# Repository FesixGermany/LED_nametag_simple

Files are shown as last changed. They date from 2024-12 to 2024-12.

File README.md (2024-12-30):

# LED nametag  

 Since many attendees are wearing some blinky LED stuff at the Chaos Communication Congress I wanted to also make myself an eye catcher  and present a little project. It was also a good opportunity to make a proper two layer PCB again to get more practice. The goal was to have the project finished or at least functional for 38C3. Since I got asked by attendees about the tag I decided to make this documentation.
 
The result is a little PCB to be worn e.g. on a collar with the outline shaped like a bone with LEDs arranged so it spells my name.
The electronics basically consists of the following:
- TP4056 lithium charger IC for a 100mAh LiPo battery
- MPM3810 DCDC converter to lower the voltage so all LEDs can be operated in parallel without a resistor
- ATtiny24 microcontroller giving PWM to the MOSFETs that switch the individual letters and the LEDs on the back
- [Paw-connect by LeoDJ](https://github.com/LeoDJ/Paw-Connect) as the ISP interface and as another eye catching feature
- Place for a photodiode to be able to adjust the brightness of the LEDs automatically depending on the surrounding

One tricky thing was to find the right voltage for the DCDC converter output so the LEDs are not too dimm at maximum brightness and not too bright as the duty cycle of the PWM would have to be extremely small on lower brightness settings and therefore one would loose the resolution for the animations.

The firmware only got to a point where I had a single simple animation running without the integration of the mentioned photodiode. That would probably require the code to be made more efficient as the memory of the controller already is quite full.
     
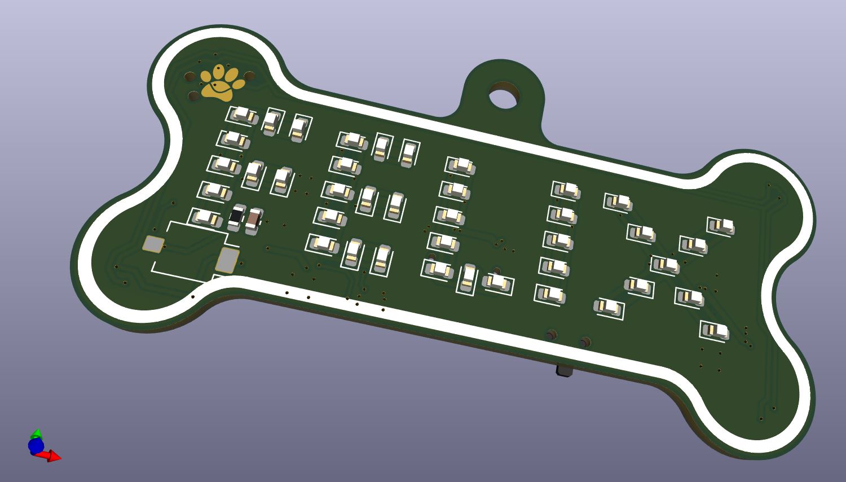
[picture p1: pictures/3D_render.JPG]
3D rendering of the PCB
   
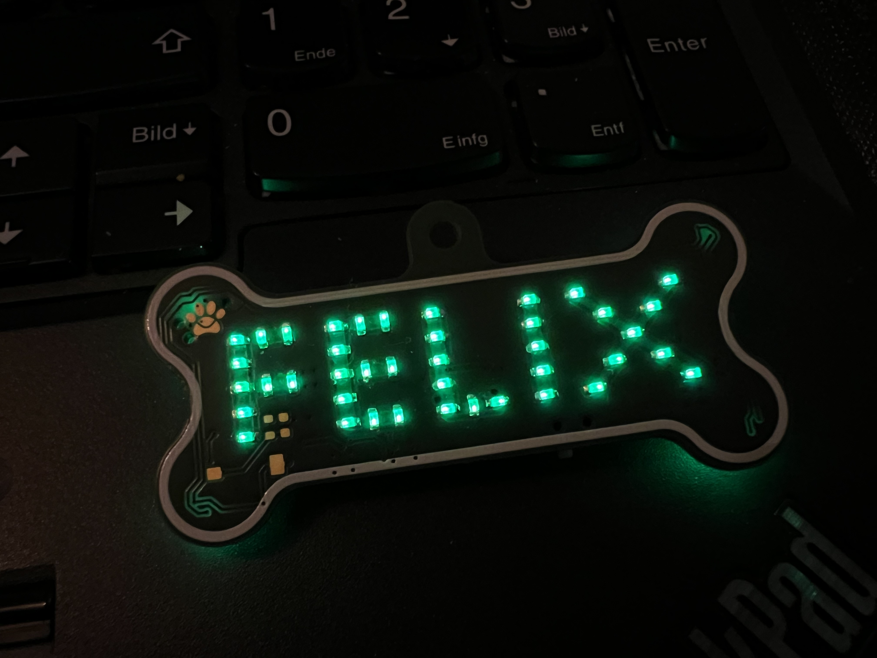
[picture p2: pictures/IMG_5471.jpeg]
Front of the PCB with lit LEDs
 
Back of the PCB with installed battery

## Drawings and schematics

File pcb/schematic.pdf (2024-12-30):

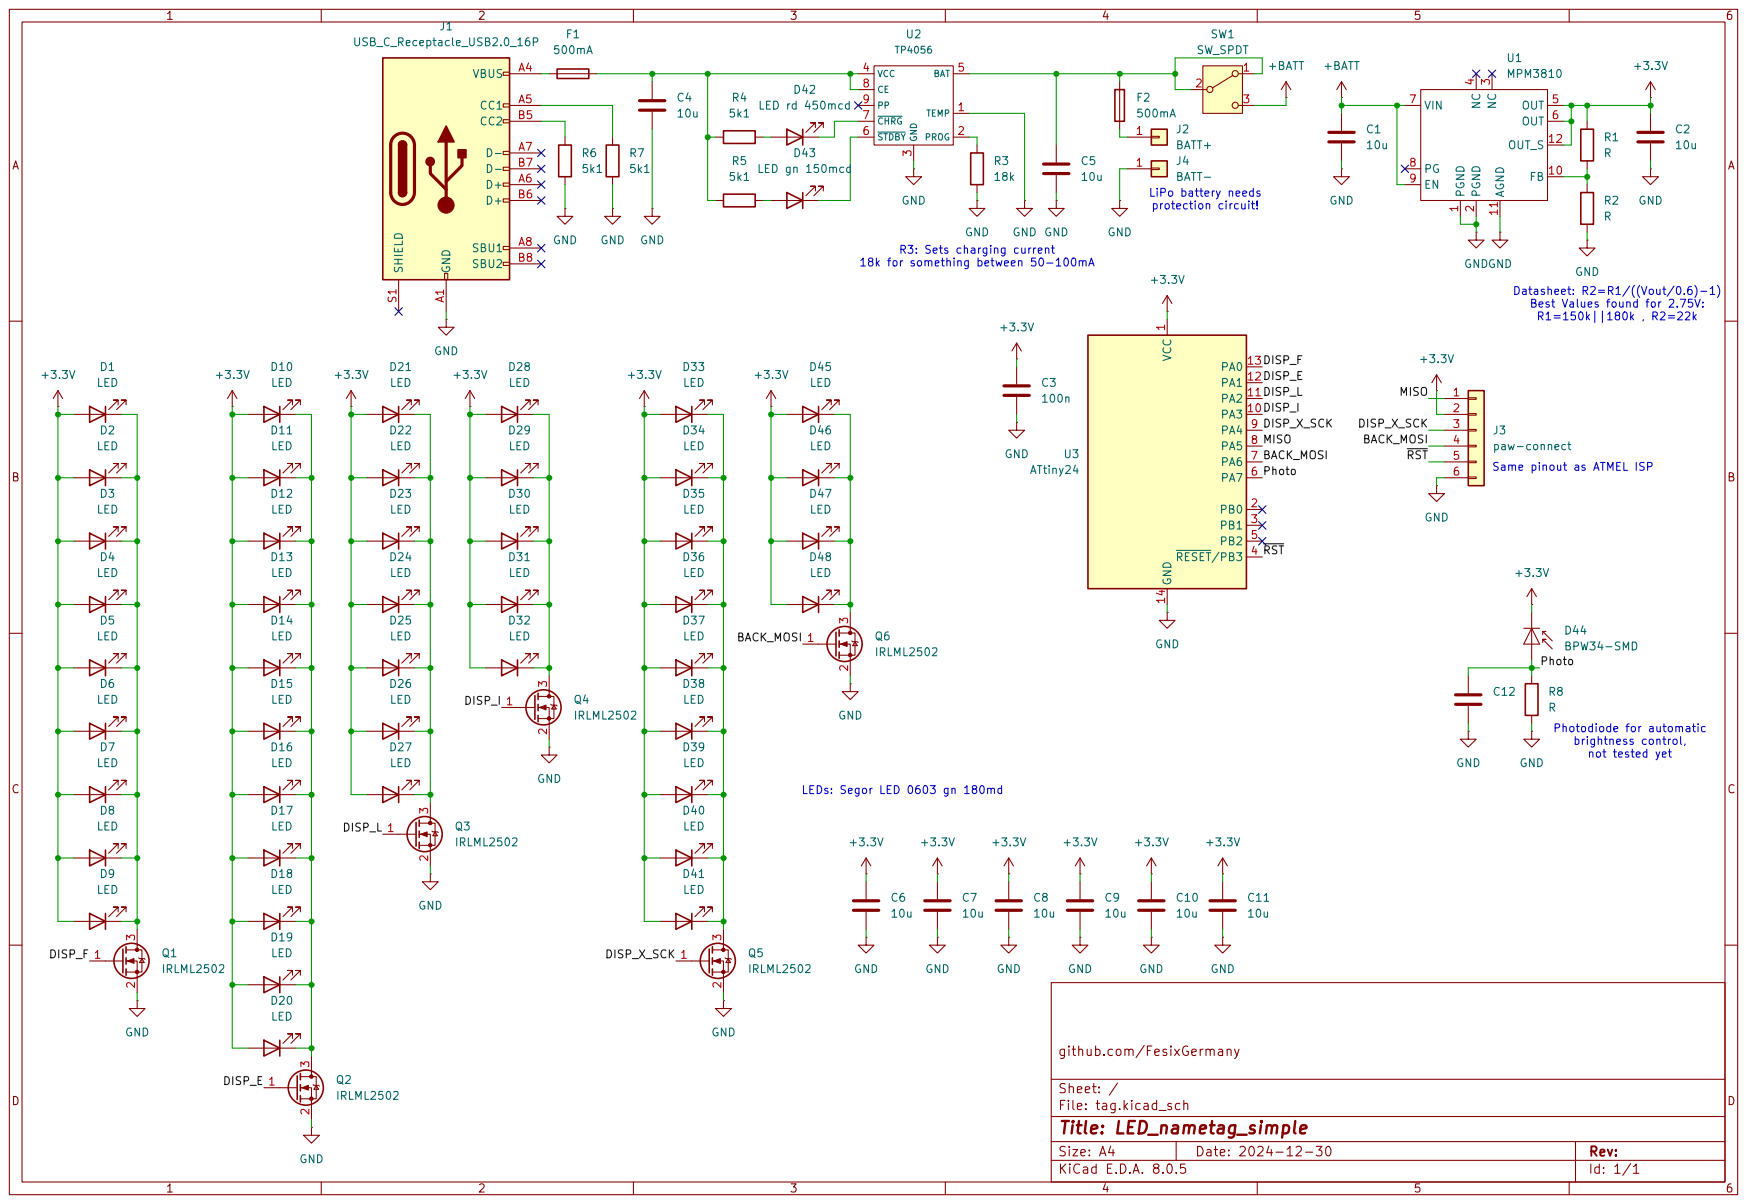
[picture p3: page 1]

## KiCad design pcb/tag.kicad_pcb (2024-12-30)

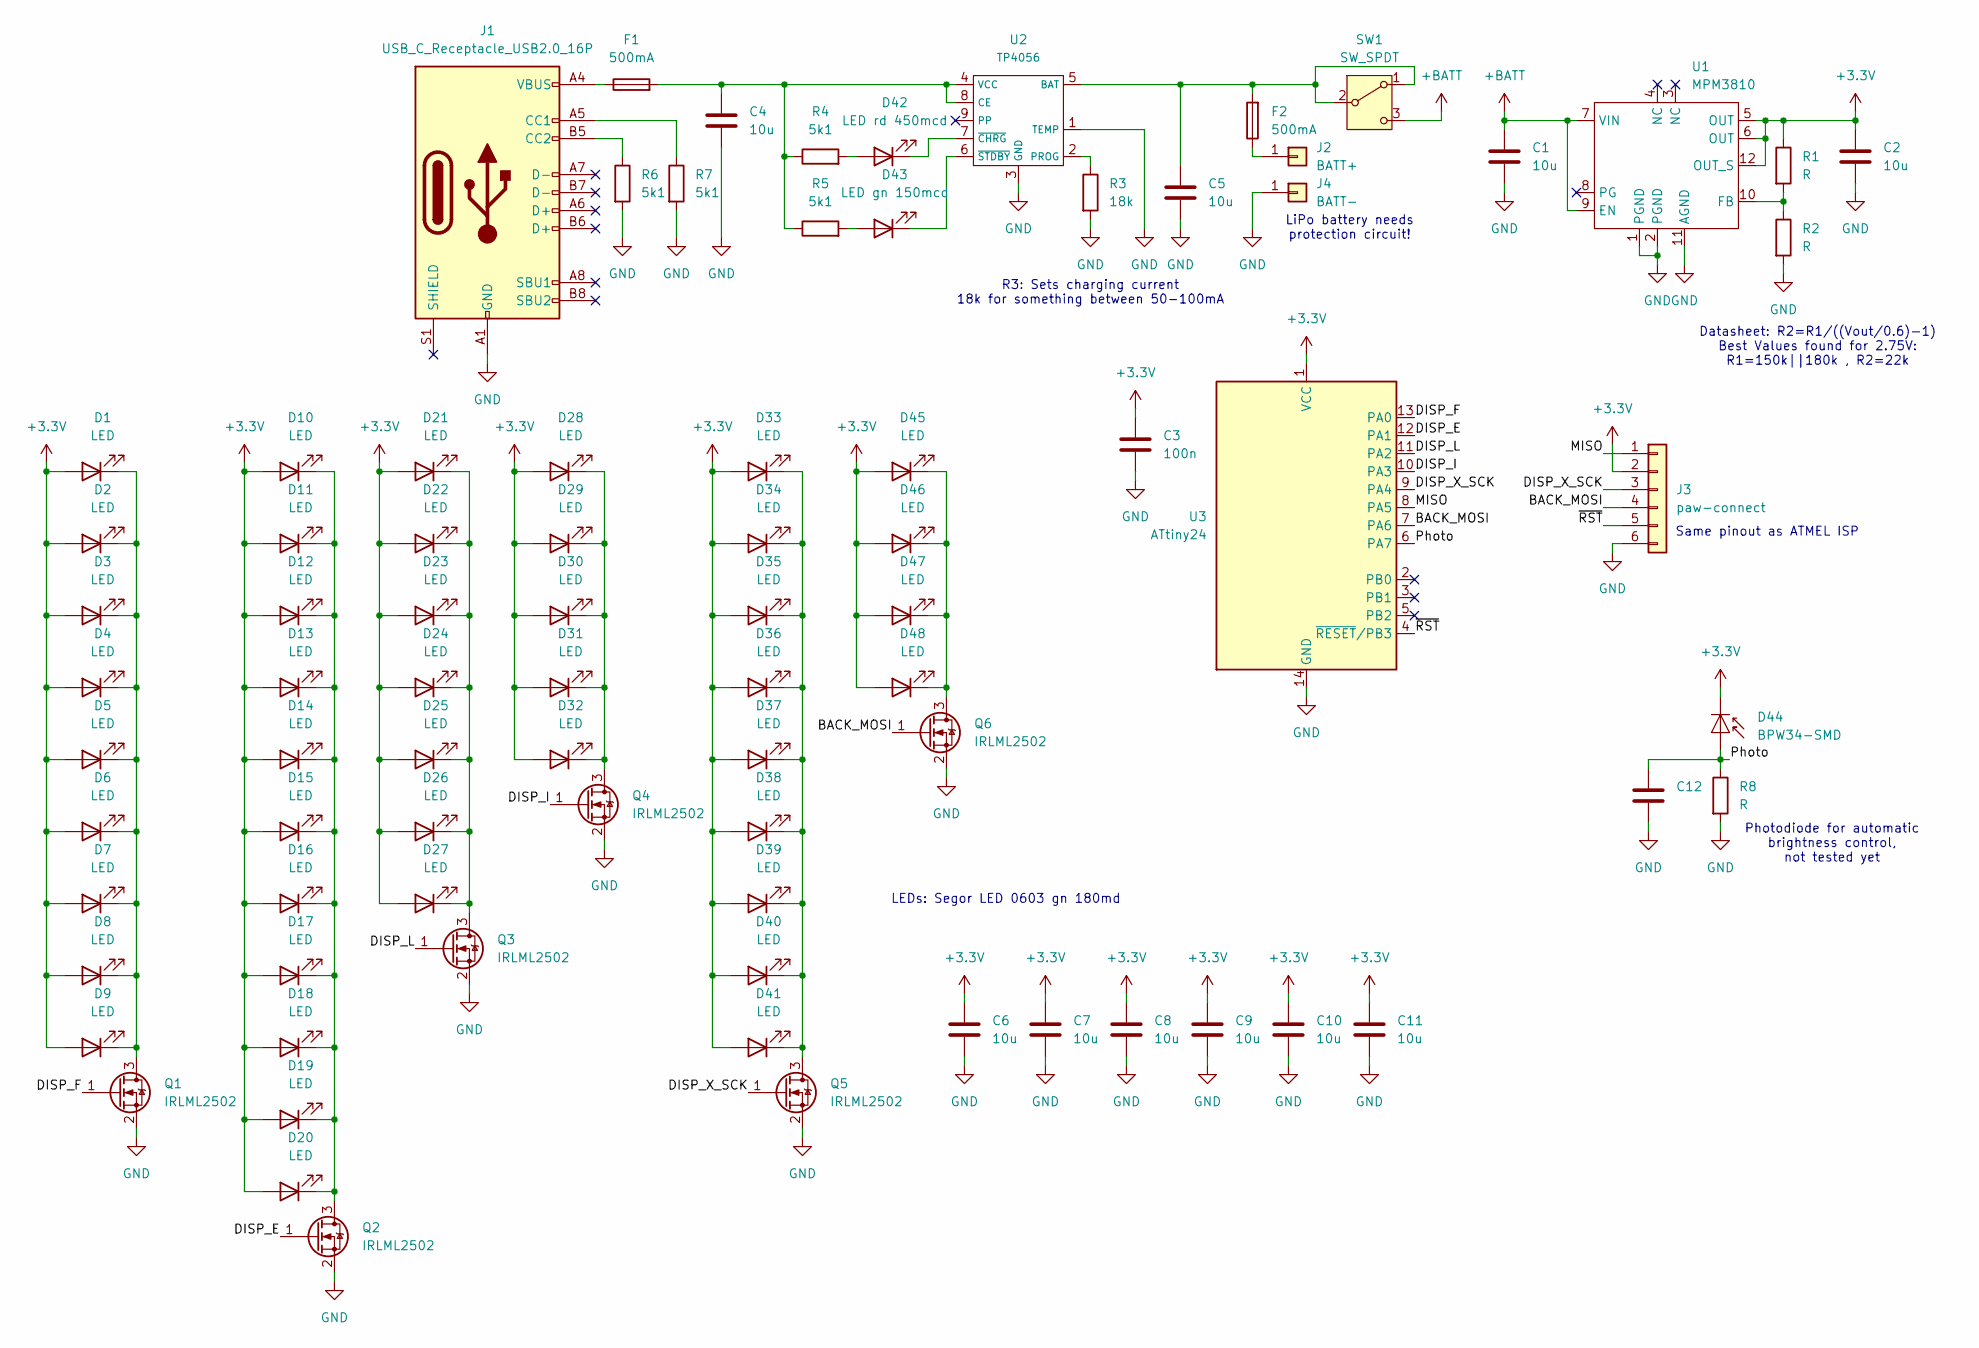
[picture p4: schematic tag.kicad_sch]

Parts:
C1, C2, C4, C5, C6, C7, C8, C9, C10, C11: 10u; C_0603_1608Metric
C3: 100n; C_0603_1608Metric
C12: C_0603_1608Metric
D1, D2, D3, D4, D5, D6, D7, D8, D9, D10, D11, D12, D13, D14, D15, D16, D17, D18, D19, D20, D21, D22, D23, D24, D25, D26, D27, D28, D29, D30, D31, D32, D33, D34, D35, D36, D37, D38, D39, D40, D41, D45, D46, D47, D48: LED; LED_0603_1608Metric
D42: LED rd 450mcd; LED_0603_1608Metric
D43: LED gn 150mcd; LED_0603_1608Metric
D44: BPW34-SMD; Osram_BPW34S-SMD
F1, F2: 500mA; Fuse_0603_1608Metric_Pad1.05x0.95mm_HandSolder
J1: USB_C_Receptacle_USB2.0_16P; USB_C_Receptacle_G-Switch_GT-USB-7010ASV
J2: BATT+; SolderWirePad_1x01_SMD_1x2mm
J3: paw-connect; Paw-Connect_RevA_TC2030-IDC-NL_2x03_P1.27mm_Vertical
J4: BATT-; SolderWirePad_1x01_SMD_1x2mm
Q1, Q2, Q3, Q4, Q5, Q6: IRLML2502; SOT-23
R1, R2, R8: R; R_0603_1608Metric
R3: 18k; R_0603_1608Metric
R4, R5, R6, R7: 5k1; R_0603_1608Metric
SW1: SW_SPDT; SW_SPDT_PCM12
U1: MPM3810
U2: TP4056; SOIC-8-1EP_3.9x4.9mm_P1.27mm_EP2.29x3mm
U3: ATtiny24; SOIC-14_3.9x8.7mm_P1.27mm

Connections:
+3.3V: C2.1, C3.1, C6.1, C7.1, C8.1, C9.1, C10.1, C11.1, D1.2 (A), D2.2 (A), D3.2 (A), D4.2 (A), D5.2 (A), D6.2 (A), D7.2 (A), D8.2 (A), D9.2 (A), D10.2 (A), D11.2 (A), D12.2 (A), D13.2 (A), D14.2 (A), D15.2 (A), D16.2 (A), D17.2 (A), D18.2 (A), D19.2 (A), D20.2 (A), D21.2 (A), D22.2 (A), D23.2 (A), D24.2 (A), D25.2 (A), D26.2 (A), D27.2 (A), D28.2 (A), D29.2 (A), D30.2 (A), D31.2 (A), D32.2 (A), D33.2 (A), D34.2 (A), D35.2 (A), D36.2 (A), D37.2 (A), D38.2 (A), D39.2 (A), D40.2 (A), D41.2 (A), D44.1 (K), D45.2 (A), D46.2 (A), D47.2 (A), D48.2 (A), J3.2, R1.1, U1.5 (OUT), U1.6 (OUT), U1.12 (OUT_S), U3.1 (VCC)
+BATT: C1.1, SW1.3 (C), U1.7 (VIN), U1.9 (EN)
/BACK_MOSI: J3.4, Q6.1 (G), U3.7 (PA6)
/DISP_E: Q2.1 (G), U3.12 (PA1)
/DISP_F: Q1.1 (G), U3.13 (PA0)
/DISP_I: Q4.1 (G), U3.10 (PA3)
/DISP_L: Q3.1 (G), U3.11 (PA2)
/DISP_X_SCK: J3.3, Q5.1 (G), U3.9 (PA4)
/MISO: J3.1, U3.8 (PA5)
/Photo: C12.1, D44.2 (A), R8.1, U3.6 (PA7)
/~RST: J3.5, U3.4 (~RESET/PB3)
GND: C1.2, C2.2, C3.2, C4.2, C5.2, C6.2, C7.2, C8.2, C9.2, C10.2, C11.2, C12.2, J1.A1 (GND), J1.A12 (GND), J1.B1 (GND), J1.B12 (GND), J3.6, J4.1, Q1.2 (S), Q2.2 (S), Q3.2 (S), Q4.2 (S), Q5.2 (S), Q6.2 (S), R2.2, R3.2, R6.2, R7.2, R8.2, U1.1 (PGND), U1.2 (PGND), U1.11 (AGND), U2.1 (TEMP), U2.3 (GND), U3.14 (GND)
unnamed: D1.1 (K), D2.1 (K), D3.1 (K), D4.1 (K), D5.1 (K), D6.1 (K), D7.1 (K), D8.1 (K), D9.1 (K), Q1.3 (D)
unnamed: D10.1 (K), D11.1 (K), D12.1 (K), D13.1 (K), D14.1 (K), D15.1 (K), D16.1 (K), D17.1 (K), D18.1 (K), D19.1 (K), D20.1 (K), Q2.3 (D)
unnamed: D21.1 (K), D22.1 (K), D23.1 (K), D24.1 (K), D25.1 (K), D26.1 (K), D27.1 (K), Q3.3 (D)
unnamed: D28.1 (K), D29.1 (K), D30.1 (K), D31.1 (K), D32.1 (K), Q4.3 (D)
unnamed: D33.1 (K), D34.1 (K), D35.1 (K), D36.1 (K), D37.1 (K), D38.1 (K), D39.1 (K), D40.1 (K), D41.1 (K), Q5.3 (D)
unnamed: D42.2 (A), R4.2
unnamed: D42.1 (K), U2.7 (~CHRG)
unnamed: D43.2 (A), R5.2
unnamed: D43.1 (K), U2.6 (~STDBY)
unnamed: D45.1 (K), D46.1 (K), D47.1 (K), D48.1 (K), Q6.3 (D)
unnamed: F1.1, J1.A4 (VBUS), J1.A9 (VBUS), J1.B4 (VBUS), J1.B9 (VBUS)
unnamed: J1.A5 (CC1), R7.1
unnamed: J1.B5 (CC2), R6.1
unnamed: F2.1, J2.1
unnamed: C5.1, F2.2, SW1.1 (A), SW1.2 (B), U2.5 (BAT)
unnamed: R1.2, R2.1, U1.10 (FB)
unnamed: C4.1, F1.2, R4.1, R5.1, U2.4 (VCC), U2.8 (CE)
unnamed: R3.1, U2.2 (PROG)

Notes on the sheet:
LiPo battery needs protection circuit!
Same pinout as ATMEL ISP
R3: Sets charging current 18k for something between 50-100mA
Datasheet: R2=R1/((Vout/0.6)-1) Best Values found for 2.75V: R1=150k||180k , R2=22k
LEDs: Segor LED 0603 gn 180md
Photodiode for automatic brightness control, not tested yet

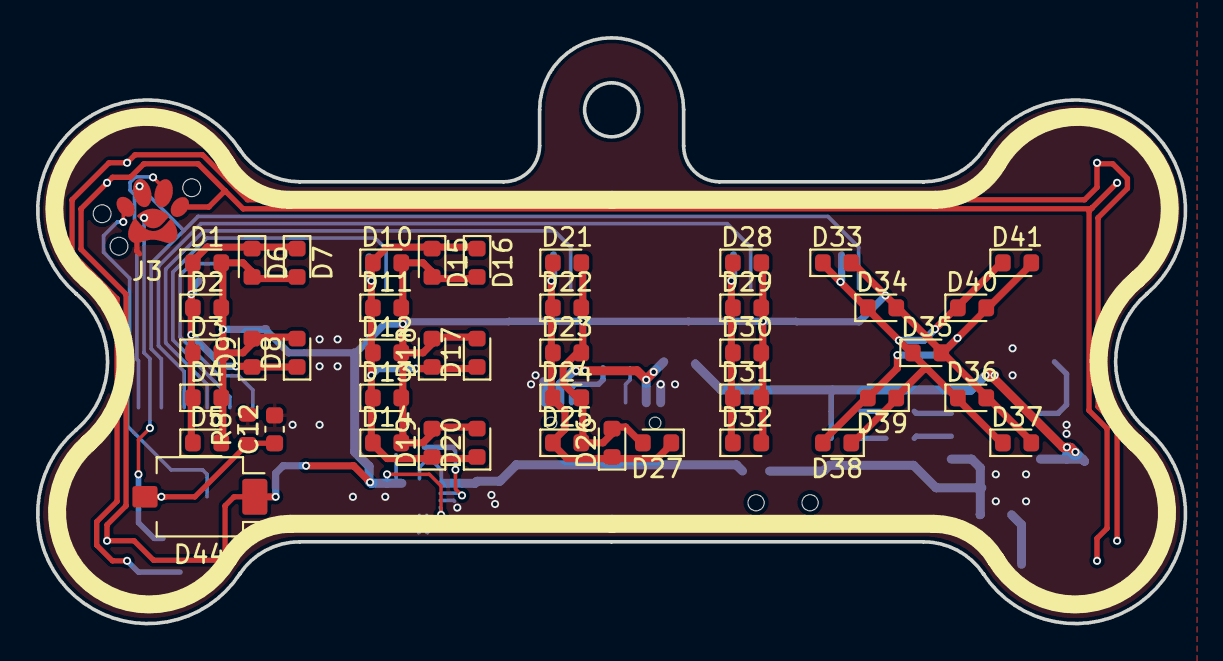
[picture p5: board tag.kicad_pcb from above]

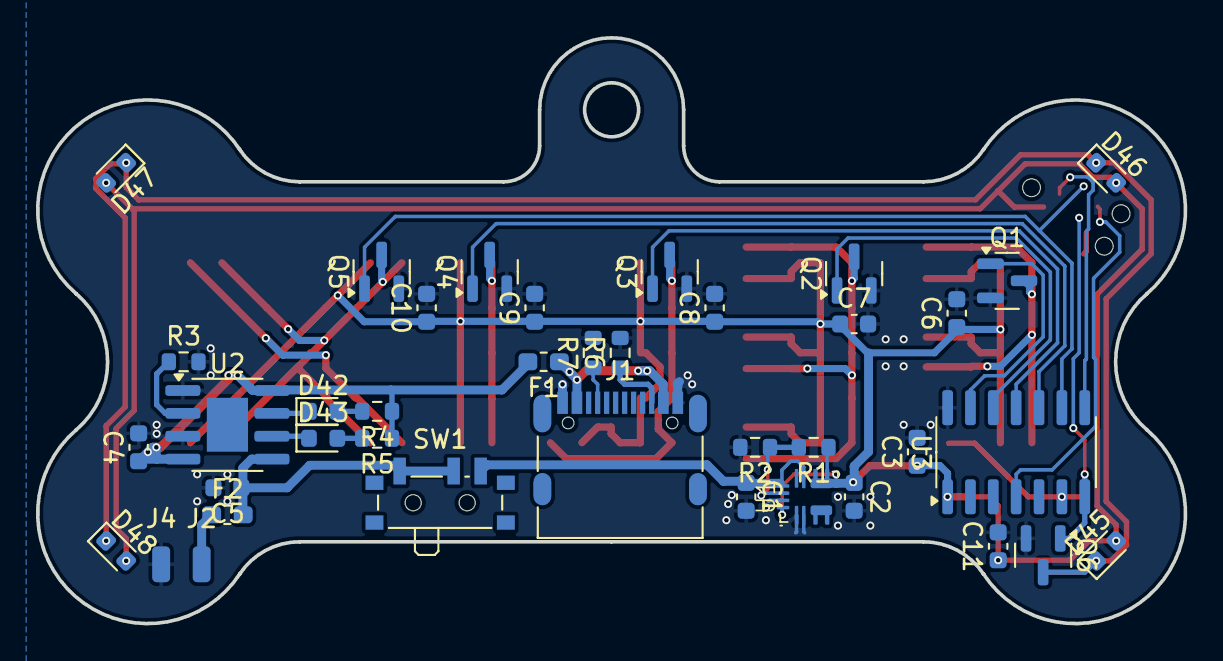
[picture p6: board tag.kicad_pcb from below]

Board: 2 copper layers, 63.8 x 32.5 mm, 84 parts (39 on the bottom side), 30 nets.

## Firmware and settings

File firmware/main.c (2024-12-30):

/*
 * tag_firmware.c
 *
 * Created: 06/12/2024 15:24:56
 * Author : felix
 */ 

#include <avr/io.h>
#include <avr/interrupt.h>

// Internal 8MHz osc without CKDIV8
#define F_CPU		8000000UL

// Outputs
#define DISP_F		0
#define DISP_E		1
#define DISP_L		2
#define DISP_I		3
#define DISP_X		4
#define LED_BACK	6

// Inputs
#define PHOTODIODE	PA7

uint8_t pwmval_F=0;
uint8_t pwmval_E=0;
uint8_t pwmval_L=0;
uint8_t pwmval_I=0;
uint8_t pwmval_X=0;
uint8_t pwmval_BACK=0;

uint8_t pwmval_F_corr=0;
uint8_t pwmval_E_corr=0;
uint8_t pwmval_L_corr=0;
uint8_t pwmval_I_corr=0;
uint8_t pwmval_X_corr=0;
uint8_t pwmval_BACK_corr=0;

float light_prescaler = 0.2;
uint8_t displaybit = 0b00000000;							// Bits corresponding to PORTA bits
volatile unsigned long tick_animation = 0;					// long is 32 bits (4.29 billion), long long is 64 bits
volatile uint8_t tick_pwm = 0;
unsigned long animation_step = 0;
unsigned long old_step = 0;


void ADC_init(void)
{
	uint16_t result;
	
	// Default VCC as reference
	//ADMUX |= (1 << REFS1) | (1 << REFS0);					// 1.1V internal reference
	
	ADCSRA = (1 << ADPS2) | (1 << ADPS1);					// 64 ADC clock prescaler
	ADCSRA |= (1 << ADEN);									// ADC enable
	
	//Dummy-Readout
	ADCSRA |= (1 << ADSC);									// ADC single conversion
	while (ADCSRA & (1 << ADSC)) {}							// Wait until conversion is finished
	
	result = ADCW;											// Read register of result and do nothing with it
}

uint16_t ADC_Read(uint8_t channel)
{
	ADMUX = (ADMUX & ~(0x1F)) | (channel & 0x1F);			// Select ADC channel without interfering with other bits in register
	ADCSRA |= (1 << ADSC);									// ADC single conversion
	while (ADCSRA & (1 << ADSC)) {}							// Wait until conversion is finished
	
	return ADCW;											// Return value
}


void animation_fillup(void)
{
	// Scale the "animation_step" from tick_animation
	// e.g. one step every 200 interrupts
	animation_step = tick_animation / 200;		// divide by 200 equals 4ms per step
	
	if (animation_step != old_step)
	{
		old_step = animation_step;

		// Each phase is 256 steps: 0..255, 256..511, etc.
		if (animation_step < 256) {
			// Phase 0
			pwmval_F   = (uint8_t)animation_step;
			pwmval_E   = 0;
			pwmval_L   = 0;
			pwmval_I   = 0;
			pwmval_X   = 0;
		}
		else if (animation_step < 512) {
			// Phase 1
			uint16_t phase = animation_step - 256;
			pwmval_F = 255;
			pwmval_E = phase;
			pwmval_L = 0;
			pwmval_I = 0;
			pwmval_X = 0;
		}
		else if (animation_step < 768) {
			// Phase 2
			uint16_t phase = animation_step - 512;
			pwmval_F = 255;
			pwmval_E = 255;
			pwmval_L = phase;
			pwmval_I = 0;
			pwmval_X = 0;
		}
		else if (animation_step < 1024) {
			// Phase 3
			uint16_t phase = animation_step - 768;
			pwmval_F = 255;
			pwmval_E = 255;
			pwmval_L = 255;
			pwmval_I = phase;
			pwmval_X = 0;
		}
		else if (animation_step < 1280) {
			// Phase 4
			uint16_t phase = animation_step - 1024;
			pwmval_F = 255;
			pwmval_E = 255;
			pwmval_L = 255;
			pwmval_I = 255;
			pwmval_X = phase;
		}
		else if (animation_step < 1536) {
			// Phase 5
			uint16_t phase = animation_step - 1280;
			pwmval_F = 255 - phase;
			pwmval_E = 255;
			pwmval_L = 255;
			pwmval_I = 255;
			pwmval_X = 255;
		}
		else if (animation_step < 1792) {
			// Phase 6
			uint16_t phase = animation_step - 1536;
			pwmval_F = 0;
			pwmval_E = 255 - phase;
			pwmval_L = 255;
			pwmval_I = 255;
			pwmval_X = 255;
		}
		else if (animation_step < 2048) {
			// Phase 7
			uint16_t phase = animation_step - 1792;
			pwmval_F = 0;
			pwmval_E = 0;
			pwmval_L = 255 - phase;
			pwmval_I = 255;
			pwmval_X = 255;
		}
		else if (animation_step < 2304) {
			// Phase 8
			uint16_t phase = animation_step - 2048;
			pwmval_F = 0;
			pwmval_E = 0;
			pwmval_L = 0;
			pwmval_I = 255 - phase;
			pwmval_X = 255;
		}
		else if (animation_step < 2560) {
			// Phase 9
			uint16_t phase = animation_step - 2304;
			pwmval_F = 0;
			pwmval_E = 0;
			pwmval_L = 0;
			pwmval_I = 0;
			pwmval_X = 255 - phase;
		}

		// Reset counter at end of animation
		if (animation_step >= 2560) {
			tick_animation = 0;
		}
	}
}

int main(void)
{
    // Outputs
	DDRA |= (1 << DISP_F) | (1 << DISP_E) | (1 << DISP_L) | (1 << DISP_I) | (1 << DISP_X) | (1 << LED_BACK);
	
	// Timer1 setup
	TCCR1B |= (1 << WGM12);						// CTC mode
	TCCR1B |= (1 << CS10);						// Prescaler 1
	OCR1A = 100;								// Top value
	TIMSK1 |= (1 << OCIE1A);					// Timer1 A interrupt enable
	
	sei();										// Enable interrupts globally
	
    while (1) 
    {
		animation_fillup();
		pwmval_BACK = 255;
		
		// Apply correction factor for maximum brightnes
		pwmval_F_corr = (int) (pwmval_F * light_prescaler);
		pwmval_E_corr = (int) (pwmval_E * light_prescaler);
		pwmval_L_corr = (int) (pwmval_L * light_prescaler);
		pwmval_I_corr = (int) (pwmval_I * light_prescaler);
		pwmval_X_corr = (int) (pwmval_X * light_prescaler);
		pwmval_BACK_corr = (int) (pwmval_BACK * light_prescaler);
	}
}


ISR (TIM1_COMPA_vect)
{		
	displaybit = 0x00;

	// Step 2: For each output, compare tick_pwm with its pwmval:
	if (tick_pwm < pwmval_F_corr)    displaybit |= (1 << DISP_F);
	if (tick_pwm < pwmval_E_corr)    displaybit |= (1 << DISP_E);
	if (tick_pwm < pwmval_L_corr)    displaybit |= (1 << DISP_L);
	if (tick_pwm < pwmval_I_corr)    displaybit |= (1 << DISP_I);
	if (tick_pwm < pwmval_X_corr)    displaybit |= (1 << DISP_X);
	if (tick_pwm < pwmval_BACK_corr) displaybit |= (1 << LED_BACK);

	// Set ports to high
	PORTA = displaybit;

	// Increment counters and reset if necessary
	tick_animation++;
	tick_pwm++;
	if (tick_pwm >= 255) tick_pwm = 0;
}
